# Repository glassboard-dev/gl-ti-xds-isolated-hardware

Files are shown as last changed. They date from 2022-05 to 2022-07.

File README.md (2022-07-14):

<p align="center">
  <h1 align="center">Isolated TI XDS Programmer</h1>
  <p align="center">
    Isolated TI & CMSIS-DAP Compatible Debugger/Programmer
  </p>
</p>

<br />
<p align="center">
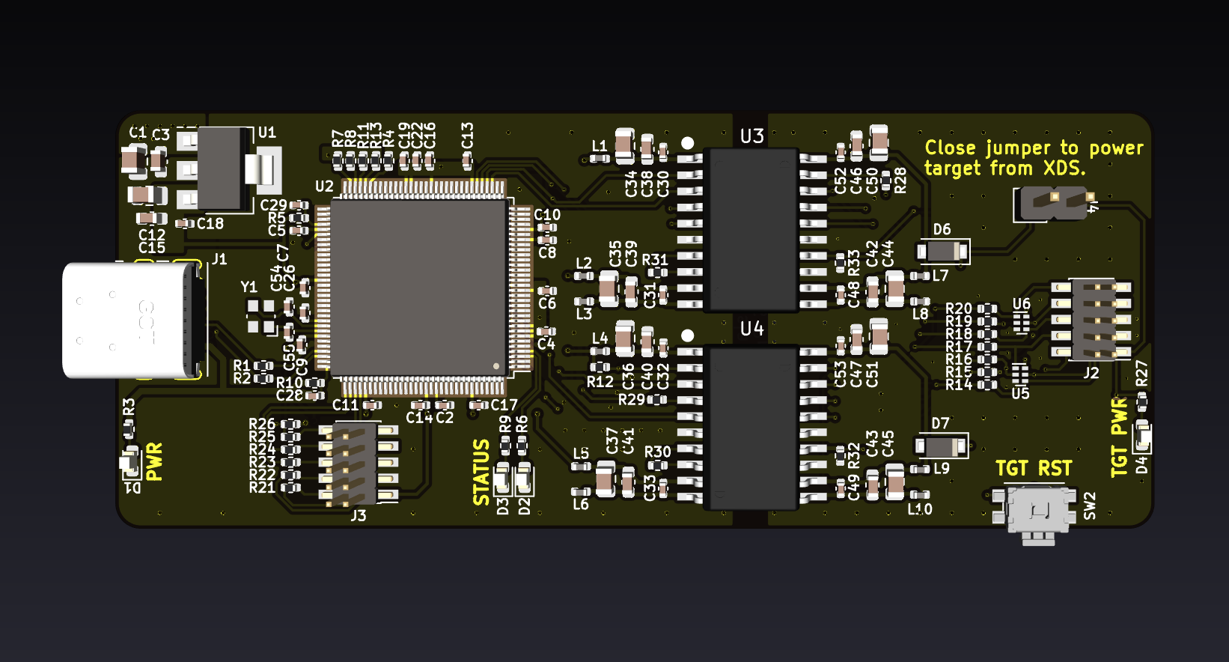
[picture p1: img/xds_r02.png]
    
<p/>



## Usage 💻
The programmer supports SWD, JTAG and cJTAG (2-wire JTAG). In addition to the programming interface, a UART connection is available over two unused pins of the 10pin programming header. These UART pins are connected back to the programmer and are available over the USB host connection as a CDC Serial port. This is useful for sending debug messages, logging and other application data from the target. The programmer also has a side fire push button that can be used for reseting the target device, as well as a jumper to supply power to the target. This is not to act as a substitution for target power, but rather a means to power and program the target micro without applying power to the entire target board.

#### CDC Serial Port
To connect the XDS serial lines to your targets UART, please reference the 10pin programming header pinout below. The current design assumes that you are creating your target hardware and have the ability to route your UART pins to the "unused" pins of the programming header.

**```NOTE - The UART switching for TX<->RX and RX<->TX is done for you on the XDS hardware. The target TX pin sould go to pin 9 of the 10pin programming header.```**

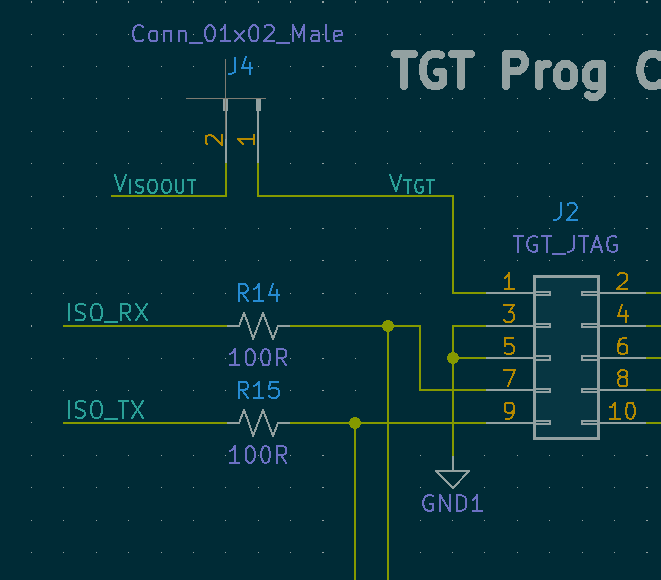
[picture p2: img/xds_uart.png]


## Development ⚡
The Isolated XDS hardware is currently developed in the open source ECAD software [KiCAD](https://www.kicad.org/). The board was created using as many of the included component symbols and footprints as possible.

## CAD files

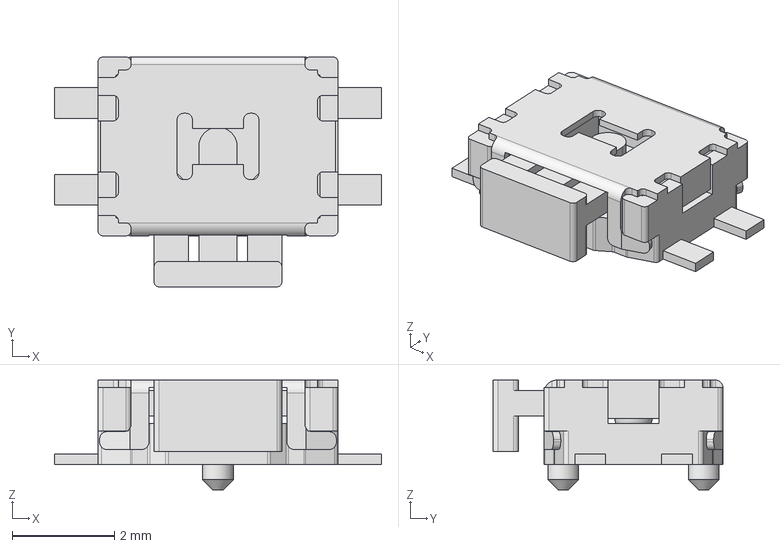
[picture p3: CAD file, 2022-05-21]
models/TL1014BF160QG/TL1014BFxxxQG.stp
6.40 x 4.50 x 2.15 mm

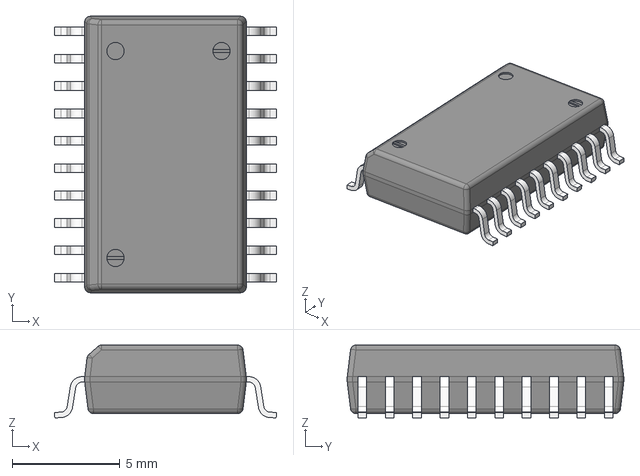
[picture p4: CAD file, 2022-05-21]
models/ul_ISOW7741FBDFMR/STEP/DFM0020A.stp
10.3 x 12.8 x 3.38 mm
BODY-SSOP
LEAD-SSOP x 20

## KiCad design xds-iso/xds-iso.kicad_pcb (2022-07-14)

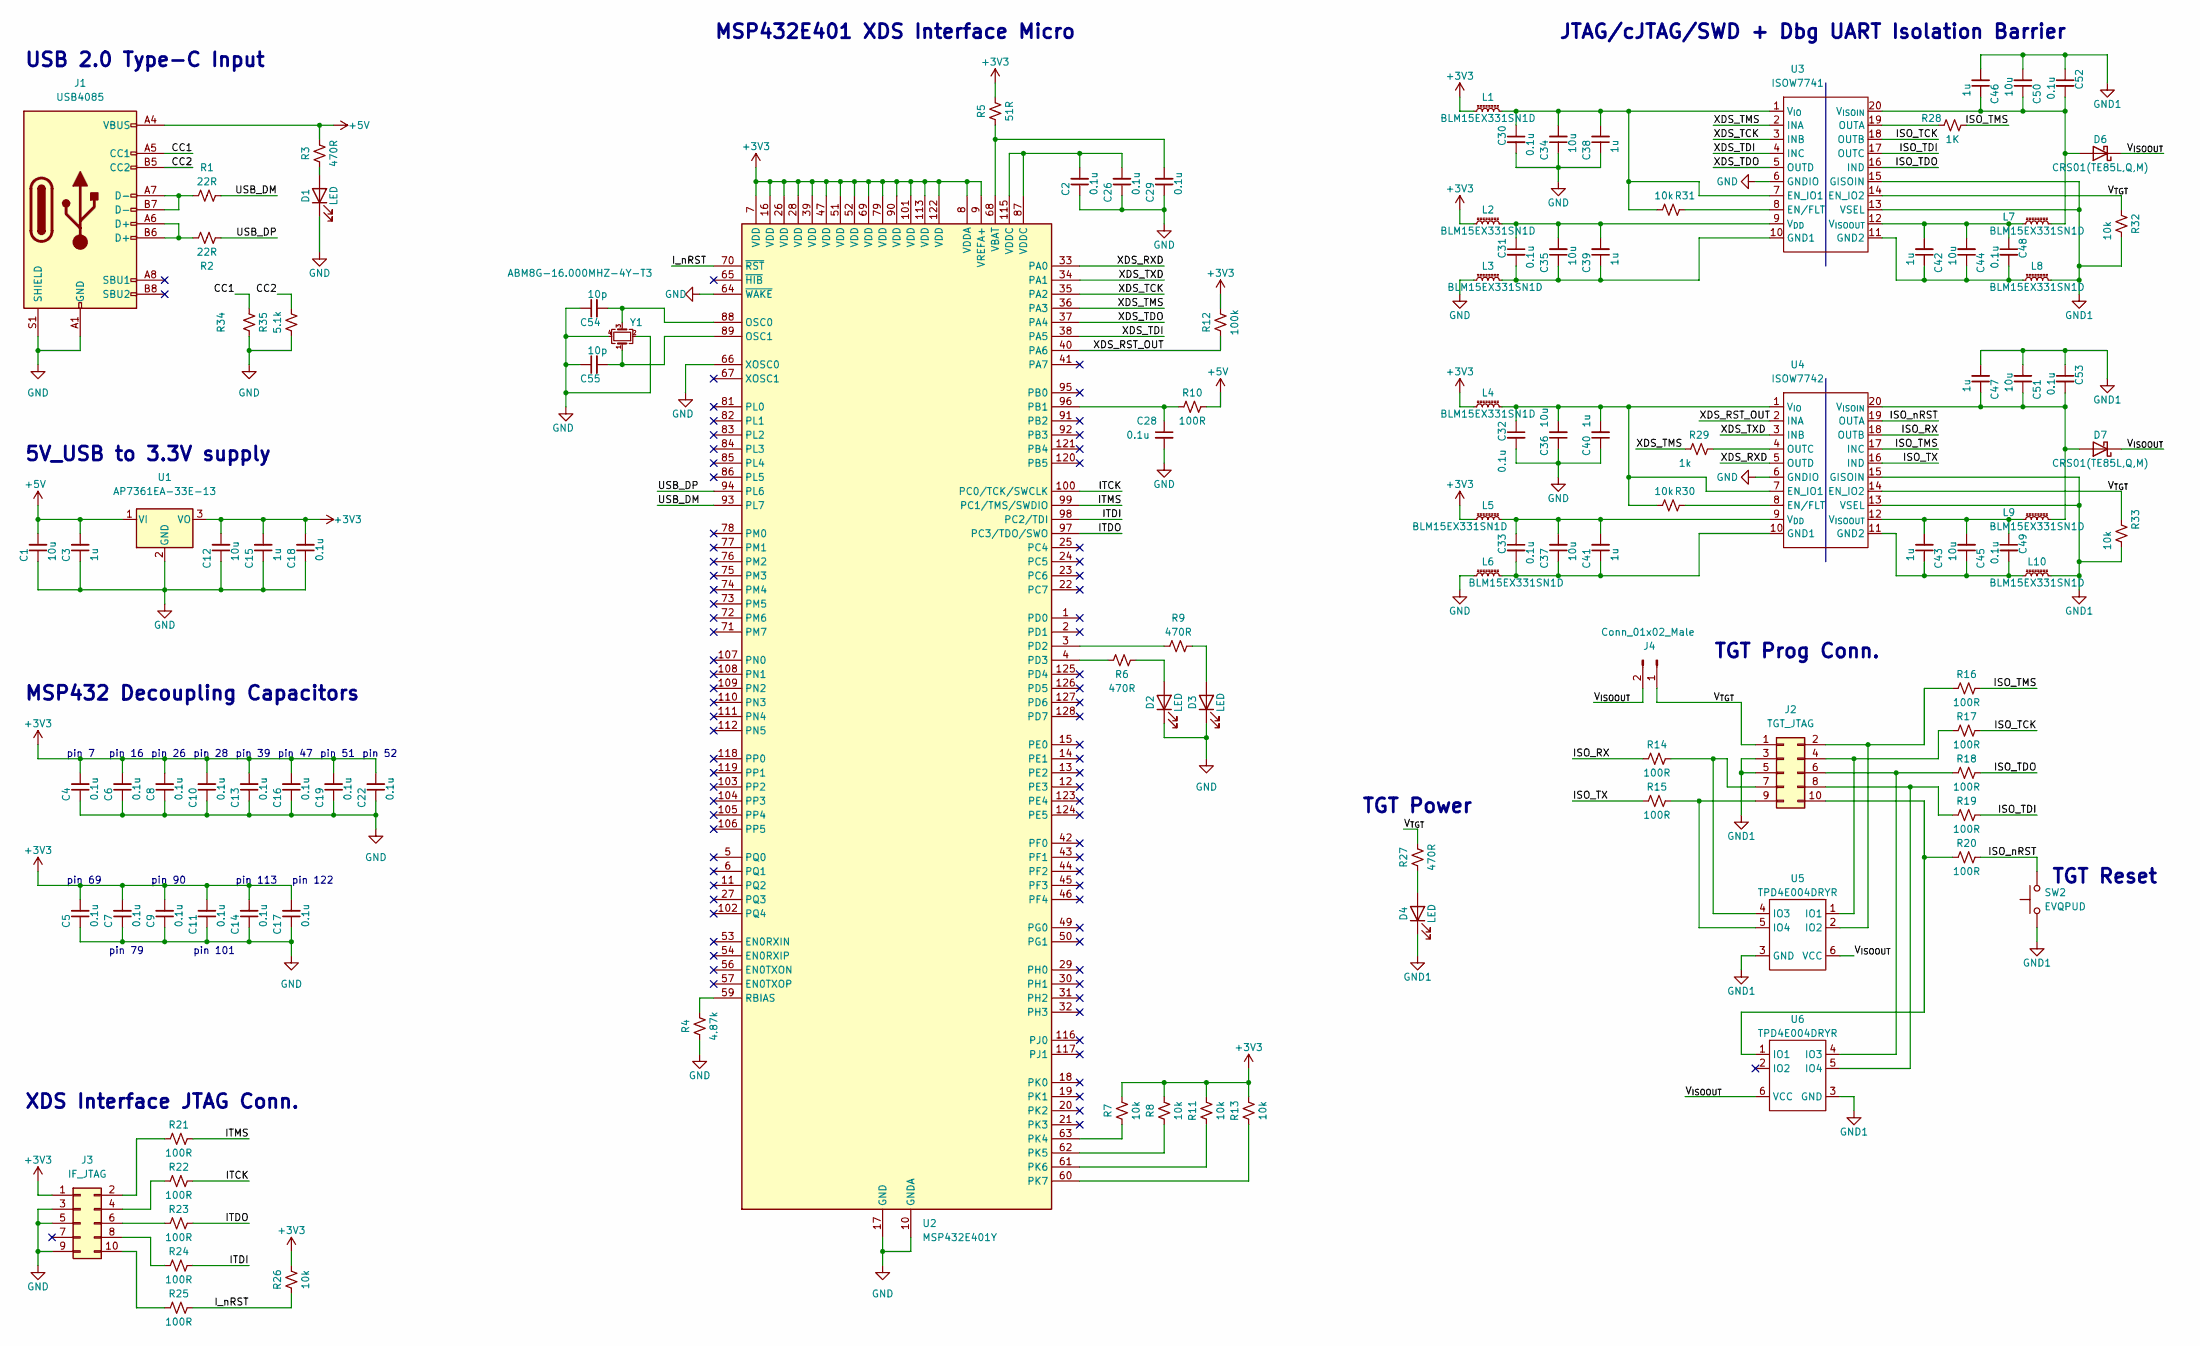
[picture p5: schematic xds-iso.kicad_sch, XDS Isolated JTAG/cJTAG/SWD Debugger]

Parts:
C1, C12, C34, C35, C36, C37, C44, C45, C50, C51: 10u; C_0805_2012Metric
C2, C4, C5, C6, C7, C8, C9, C10, C11, C13, C14, C16, C17, C18, C19, C22, C26, C28, C29, C30, C31, C32, C33, C48, C49, C52, C53: 0.1u; C_0402_1005Metric
C3, C15, C38, C39, C40, C41, C42, C43, C46, C47: 1u; C_0603_1608Metric
C54, C55: 10p; C_0402_1005Metric
D1, D2, D3, D4: LED; LED_0603_1608Metric
D6, D7: CRS01(TE85L,Q,M); D_SOD-123F
J1: USB4085; USB_C_Receptacle_GCT_USB4085
J2: TGT_JTAG; PinHeader_2x05_P1.27mm_Vertical_SMD
J3: IF_JTAG; PinHeader_2x05_P1.27mm_Vertical_SMD
J4: Conn_01x02_Male; PinHeader_1x02_P2.54mm_Vertical
L1, L2, L3, L4, L5, L6, L7, L8, L9, L10: BLM15EX331SN1D; L_0402_1005Metric
R1, R2: 22R; R_0402_1005Metric
R3, R6, R9, R27: 470R; R_0402_1005Metric
R4: 4.87k; R_0402_1005Metric
R5: 51R; R_0402_1005Metric
R7, R8, R11, R13, R26, R30, R31, R32, R33: 10k; R_0402_1005Metric
R10, R14, R15, R16, R17, R18, R19, R20, R21, R22, R23, R24, R25: 100R; R_0402_1005Metric
R12: 100k; R_0402_1005Metric
R28: 1K; R_0402_1005Metric
R29: 1k; R_0402_1005Metric
R34: R_0402_1005Metric
R35: 5.1k; R_0402_1005Metric
SW2: EVQPUD; Panasonic_EVQPUM_EVQPUD
U1: AP7361EA-33E-13; SOT-223-3_TabPin2
U2: MSP432E401Y; LQFP-128_14x14mm_P0.4mm
U3: ISOW7741; SOIC-20
U4: ISOW7742; SOIC-20
U5, U6: TPD4E004DRYR; Fairchild_MicroPak-6_1.0x1.45mm_P0.5mm
Y1: ABM8G-16.000MHZ-4Y-T3; Crystal_SMD_Abracon_ABM10-4Pin_2.5x2.0mm

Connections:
+3V3: C4.2, C5.2, C6.2, C7.2, C8.2, C9.2, C10.2, C11.2, C12.2, C13.2, C14.2, C15.2, C16.2, C17.2, C18.2, C19.2, C22.2, J3.1, L1.1, L2.1, L4.1, L5.1, R5.2, R7.2, R8.2, R11.2, R12.2, R13.2, R26.2, U1.3 (VO), U2.7 (VDD), U2.8 (VDDA), U2.9 (VREFA+), U2.16 (VDD), U2.26 (VDD), U2.28 (VDD), U2.39 (VDD), U2.47 (VDD), U2.51 (VDD), U2.52 (VDD), U2.69 (VDD), U2.79 (VDD), U2.90 (VDD), U2.101 (VDD), U2.113 (VDD), U2.122 (VDD)
+5V: C1.2, C3.2, J1.A4 (VBUS), J1.A9 (VBUS), J1.B4 (VBUS), J1.B9 (VBUS), R3.2, R10.2, U1.1 (VI)
/CC1: J1.A5 (CC1), R34.2
/CC2: J1.B5 (CC2), R35.2
/ISO_RX: R14.1, U4.18 (OUTB)
/ISO_TCK: R17.2, U3.18 (OUTB)
/ISO_TDI: R19.2, U3.17 (OUTC)
/ISO_TDO: R18.2, U3.16 (IND)
/ISO_TMS: R16.2, R28.2, U4.17 (INC)
/ISO_TX: R15.1, U4.16 (IND)
/ISO_nRST: R20.2, SW2.2, U4.19 (OUTA)
/ITCK: R22.2, U2.100 (PC0/TCK/SWCLK)
/ITDI: R24.2, U2.98 (PC2/TDI)
/ITDO: R23.2, U2.97 (PC3/TDO/SWO)
/ITMS: R21.2, U2.99 (PC1/TMS/SWDIO)
/I_nRST: R25.2, R26.1, U2.70 (~RST)
/USB_DM: R1.2, U2.93 (PL7)
/USB_DP: R2.1, U2.94 (PL6)
/V_{ISOOUT}: D6.1 (K), D7.1 (K), J4.2, U5.6 (VCC), U6.6 (VCC)
/V_{TGT}: J2.1, J4.1, R27.2, R32.1, R33.1, U3.14 (EN_IO2), U4.14 (EN_IO2)
/XDS_RST_OUT: R12.1, U2.40 (PA6), U4.2 (INA)
/XDS_RXD: U2.33 (PA0), U4.5 (OUTD)
/XDS_TCK: U2.35 (PA2), U3.3 (INB)
/XDS_TDI: U2.38 (PA5), U3.4 (INC)
/XDS_TDO: U2.37 (PA4), U3.5 (OUTD)
/XDS_TMS: R29.1, U2.36 (PA3), U3.2 (INA)
/XDS_TXD: U2.34 (PA1), U4.3 (INB)
GND: C1.1, C2.1, C3.1, C4.1, C5.1, C6.1, C7.1, C8.1, C9.1, C10.1, C11.1, C12.1, C13.1, C14.1, C15.1, C16.1, C17.1, C18.1, C19.1, C22.1, C26.1, C28.2, C29.1, C30.2, C32.2, C34.1, C36.1, C38.1, C40.1, C54.1, C55.1, D1.1 (K), D2.1 (K), D3.1 (K), J1.A1 (GND), J1.A12 (GND), J1.B1 (GND), J1.B12 (GND), J1.S1 (SHIELD), J3.3, J3.5, J3.9, L3.1, L6.1, R4.1, R34.1, R35.1, U1.2 (GND), U2.10 (GNDA), U2.17 (GND), U2.48 (GND), U2.55 (GND), U2.58 (GND), U2.64 (~WAKE), U2.66 (XOSC0), U2.80 (GND), U2.114 (GND), U3.6 (GNDIO), U4.6 (GNDIO), Y1.2, Y1.4
GND1: C46.2, C47.2, C50.2, C51.2, C52.1, C53.1, D4.1 (K), J2.3, J2.5, L8.1, L10.1, R32.2, R33.2, SW2.1, U3.13 (VSEL), U3.15 (GISOIN), U4.13 (VSEL), U4.15 (GISOIN), U5.3 (GND), U6.3 (GND)
unnamed: C2.2, C26.2, U2.87 (VDDC), U2.115 (VDDC)
unnamed: C28.1, R10.1, U2.96 (PB1)
unnamed: C29.2, R5.1, U2.68 (VBAT)
unnamed: C30.1, C34.2, C38.2, L1.2, R31.2, U3.1 (V_{IO}), U3.7 (EN_IO1)
unnamed: C31.1, C35.2, C39.2, L2.2, U3.9 (V_{DD})
unnamed: C31.2, C35.1, C39.1, L3.2, U3.10 (GND1)
unnamed: C32.1, C36.2, C40.2, L4.2, R30.2, U4.1 (V_{IO}), U4.7 (EN_IO1)
unnamed: C33.1, C37.2, C41.2, L5.2, U4.9 (V_{DD})
unnamed: C33.2, C37.1, C41.1, L6.2, U4.10 (GND1)
unnamed: C42.1, C44.1, C48.2, L8.2, U3.11 (GND2)
unnamed: C42.2, C44.2, C48.1, L7.2, U3.12 (V_{ISOOUT})
unnamed: C43.1, C45.1, C49.2, L10.2, U4.11 (GND2)
unnamed: C43.2, C45.2, C49.1, L9.2, U4.12 (V_{ISOOUT})
unnamed: C46.1, C50.1, C52.2, D6.2 (A), L7.1, U3.20 (V_{ISOIN})
unnamed: C47.1, C51.1, C53.2, D7.2 (A), L9.1, U4.20 (V_{ISOIN})
unnamed: C54.2, U2.88 (OSC0), Y1.3
unnamed: C55.2, U2.89 (OSC1), Y1.1
unnamed: D1.2 (A), R3.1
unnamed: D2.2 (A), R6.2
unnamed: D3.2 (A), R9.2
unnamed: D4.2 (A), R27.1
unnamed: J1.A6 (D+), J1.B6 (D+), R2.2
unnamed: J1.A7 (D-), J1.B7 (D-), R1.1
unnamed: J2.2, R16.1, U5.2 (IO2)
unnamed: J2.4, R17.1, U5.1 (IO1)
unnamed: J2.6, R18.1, U6.4 (IO3)
unnamed: J2.7, R14.2, U5.4 (IO3)
unnamed: J2.8, R19.1, U6.5 (IO4)
unnamed: J2.9, R15.2, U5.5 (IO4)
unnamed: J2.10, R20.1, U6.1 (IO1)
unnamed: J3.2, R21.1
unnamed: J3.4, R22.1
unnamed: J3.6, R23.1
unnamed: J3.8, R24.1
unnamed: J3.10, R25.1
unnamed: R4.2, U2.59 (RBIAS)
unnamed: R6.1, U2.4 (PD3)
unnamed: R7.1, U2.63 (PK4)
unnamed: R8.1, U2.62 (PK5)
unnamed: R9.1, U2.3 (PD2)
unnamed: R11.1, U2.61 (PK6)
unnamed: R13.1, U2.60 (PK7)
unnamed: R28.1, U3.19 (OUTA)
unnamed: R29.2, U4.4 (OUTC)
unnamed: R30.1, U4.8 (EN/FLT)
unnamed: R31.1, U3.8 (EN/FLT)

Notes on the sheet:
TGT Reset
pin 113
pin 90
MSP432E401 XDS Interface Micro
pin 16
pin 52
USB 2.0 Type-C Input
JTAG/cJTAG/SWD + Dbg UART Isolation Barrier
TGT Power
MSP432 Decoupling Capacitors
pin 47
pin 51
pin 69
pin 7
pin 101
TGT Prog Conn.
pin 122
XDS Interface JTAG Conn.
pin 26
pin 79
pin 28
pin 39
5V_USB to 3.3V supply

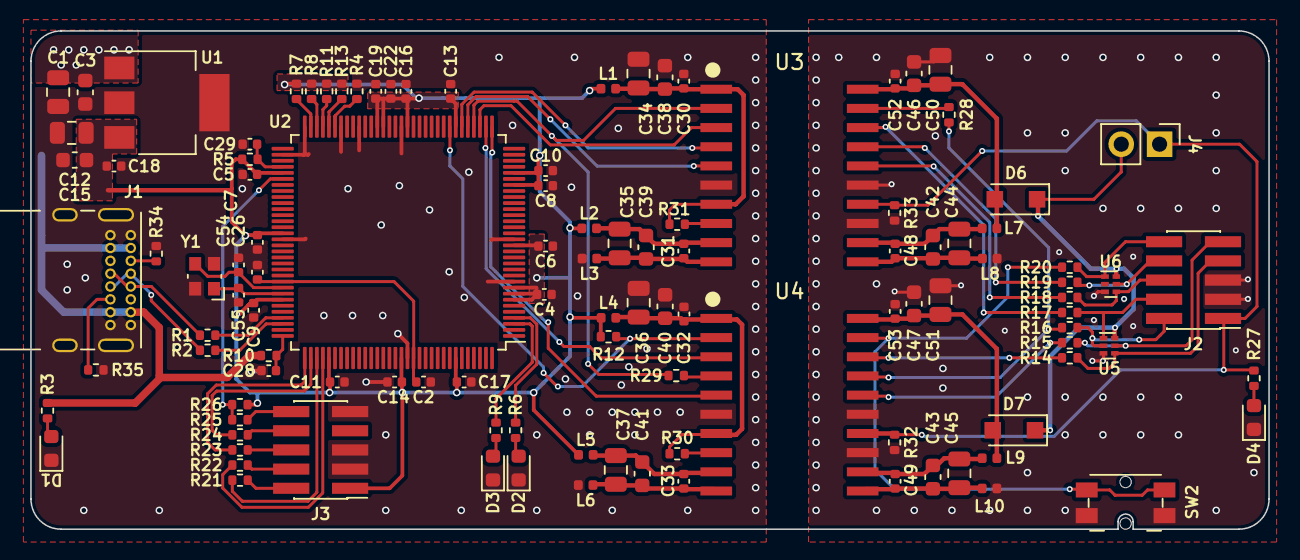
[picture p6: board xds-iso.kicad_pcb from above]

Board: 2 copper layers, 82.0 x 33.0 mm, 112 parts (0 on the bottom side), 75 nets.

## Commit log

2022-05-21 R01 first commit
    [DFM0020A.stp, TL1014BFxxxQG.stp, xds-iso.kicad_pcb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]
2022-05-23 Remove soldermask between the MSP432 IC pads
    [xds-iso.kicad_pcb]
2022-06-29 R02 updates supporting cJTAG and SWD
    [xds-iso.kicad_pcb, xds-iso.kicad_sch]
2022-07-13 Changed TMS series resistor to 1k
    [xds-iso.kicad_pcb, xds-iso.kicad_sch]
2022-07-13 Add images and update README
    [xds-iso.kicad_sch]
2022-07-13 Final schematic touches
    [xds-iso.kicad_sch]
2022-07-14 Added 5.1k pulldowns to the CC1 and CC2 pins to comply with USB Type C spec
    [xds-iso.kicad_pcb, xds-iso.kicad_sch]

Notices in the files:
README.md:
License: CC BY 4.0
